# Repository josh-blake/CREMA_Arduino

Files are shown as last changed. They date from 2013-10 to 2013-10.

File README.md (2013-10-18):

CREMA
=====

ControlleR for Espresso MAchines (http://josh.to/crema)

This entire project (including hardware and software) is distrubuted under the Creative Commons Attribution-NonCommercial-ShareAlike 3.0 Unported License.
http://creativecommons.org/licenses/by-nc-sa/3.0/deed.en_US

Please contact crema at josh dot to if you have any specific questions or would like to contribute to this project.

Enjoy the espresso.

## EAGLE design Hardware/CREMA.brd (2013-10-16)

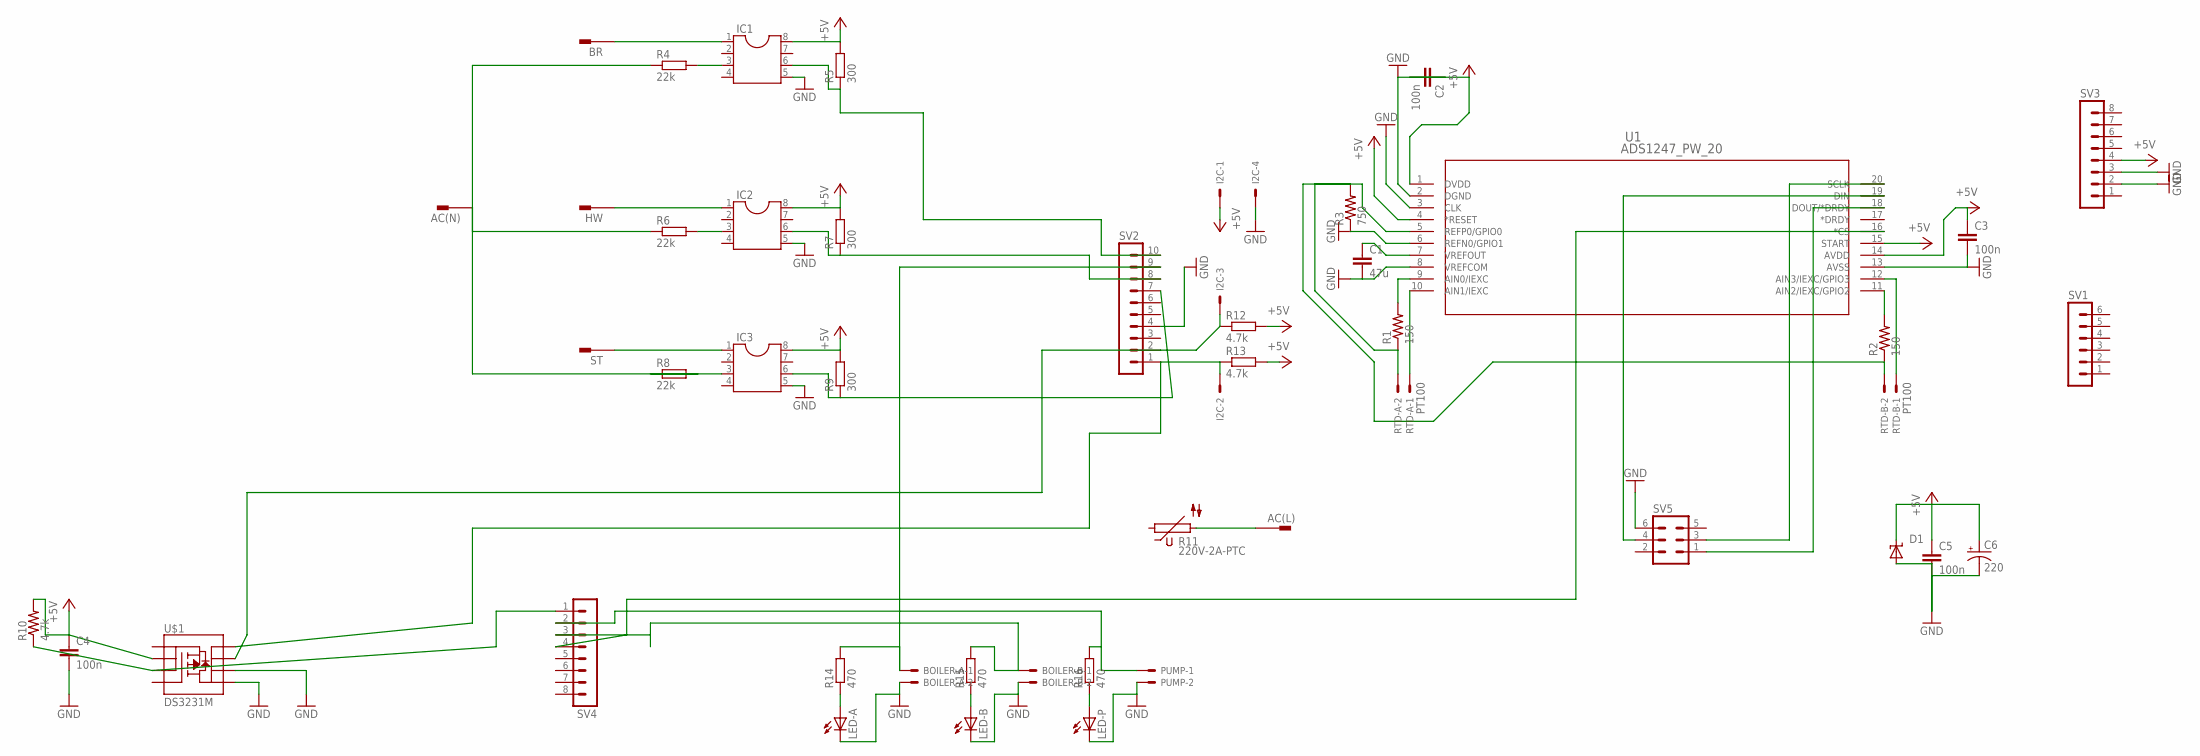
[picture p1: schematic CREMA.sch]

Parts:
AC(L): PIN262409-1; 62409-1
AC(N): PIN262409-1; 62409-1
BOILER-A: C-GRID-02-70543; 70543-02
BOILER-B: C-GRID-02-70543; 70543-02
BR: PIN262409-1; 62409-1
C1: 47u; C0805
C2, C3, C4, C5: 100n; C0805
C6: 220; D/7343-31W
D1: SUPPRESSOR-SMBJ; SMBJ
HW: PIN262409-1; 62409-1
I2C: C-GRID-04-70543; 70543-04
IC1, IC2, IC3: DIL8; DIL08
LED-A: LEDSML0603; SML0603
LED-B: LEDSML0603; SML0603
LED-P: LEDSML0603; SML0603
PUMP: C-GRID-02-70543; 70543-02
R1, R2: 150; R0603
R3: 750; R0603
R4, R6, R8: 22k; R1206
R5, R7, R9: 300; R1206
R10, R12, R13: 4.7k; R0603
R11: 220V-2A-PTC; S20K11
R14, R15, R16: 470; R0603
RTD-A: PT100; 70543-02
RTD-B: PT100; 70543-02
ST: PIN262409-1; 62409-1
SV1: MA06-1
SV2: MA10-1
SV3, SV4: MA08-1
SV5: MA03-2
U1: ADS1247_PW_20; PW20
U$1: DS3231M; SO08

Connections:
+5V: C2.2, C3.1, C4.1, C5.1, C6.+, D1.C, I2C.1, IC1.8, IC2.8, IC3.8, R5.2, R7.2, R9.2, R10.2, R12.2, R13.2, SV3.4, U1.1 (DVDD), U1.4 (*RESET), U1.14 (AVDD), U1.15 (START), U$1.2 (S)
GND: BOILER-A.2, BOILER-B.2, C1.2, C2.1, C3.2, C4.2, C5.2, C6.-, D1.A, I2C.4, IC1.5, IC2.5, IC3.5, LED-A.C, LED-B.C, LED-P.C, PUMP.2, R3.1, SV2.4, SV3.2, SV3.3, SV5.6, U1.2 (DGND), U1.3 (CLK), U1.6 (REFN0/GPIO1), U1.8 (VREFCOM), U1.13 (AVSS), U$1.5 (D), U$1.6 (D)
unnamed: I2C.3, R12.1, SV2.2, U$1.7 (D)
unnamed: C1.1, U1.7 (VREFOUT)
unnamed: RTD-A.1, U1.10 (AIN1/IEXC)
unnamed: R1.1, R2.1, R3.2, RTD-A.2, RTD-B.2, U1.5 (REFP0/GPIO0)
unnamed: R1.2, U1.9 (AIN0/IEXC)
unnamed: R2.2, U1.11 (AIN2/IEXC/GPIO2)
unnamed: RTD-B.1, U1.12 (AIN3/IEXC/GPIO3)
unnamed: BR.A1, BR.A2, IC1.1
unnamed: IC1.3, R4.2
unnamed: IC1.6, R5.1, SV2.10
unnamed: HW.A1, HW.A2, IC2.1
unnamed: IC2.3, R6.2
unnamed: IC2.6, R7.1, SV2.8
unnamed: IC3.1, ST.A1, ST.A2
unnamed: IC3.3, R8.1
unnamed: IC3.6, R9.1, SV2.7
unnamed: AC(N).A1, AC(N).A2, R4.1, R6.1, R8.2
unnamed: R10.1, SV4.1, U$1.3 (S)
unnamed: AC(L).A1, AC(L).A2, R11.2
unnamed: LED-A.A, R14.1
unnamed: SV4.4, U1.16 (*CS)
unnamed: SV5.1, U1.18 (DOUT/*DRDY)
unnamed: SV5.3, U1.20 (SCLK)
unnamed: SV5.4, U1.19 (DIN)
unnamed: I2C.2, R13.1, SV2.1, U$1.8 (D)
unnamed: BOILER-A.1, R14.2, SV2.9
unnamed: BOILER-B.1, R15.2, SV4.3
unnamed: PUMP.1, R16.2, SV4.2
unnamed: LED-B.A, R15.1
unnamed: LED-P.A, R16.1

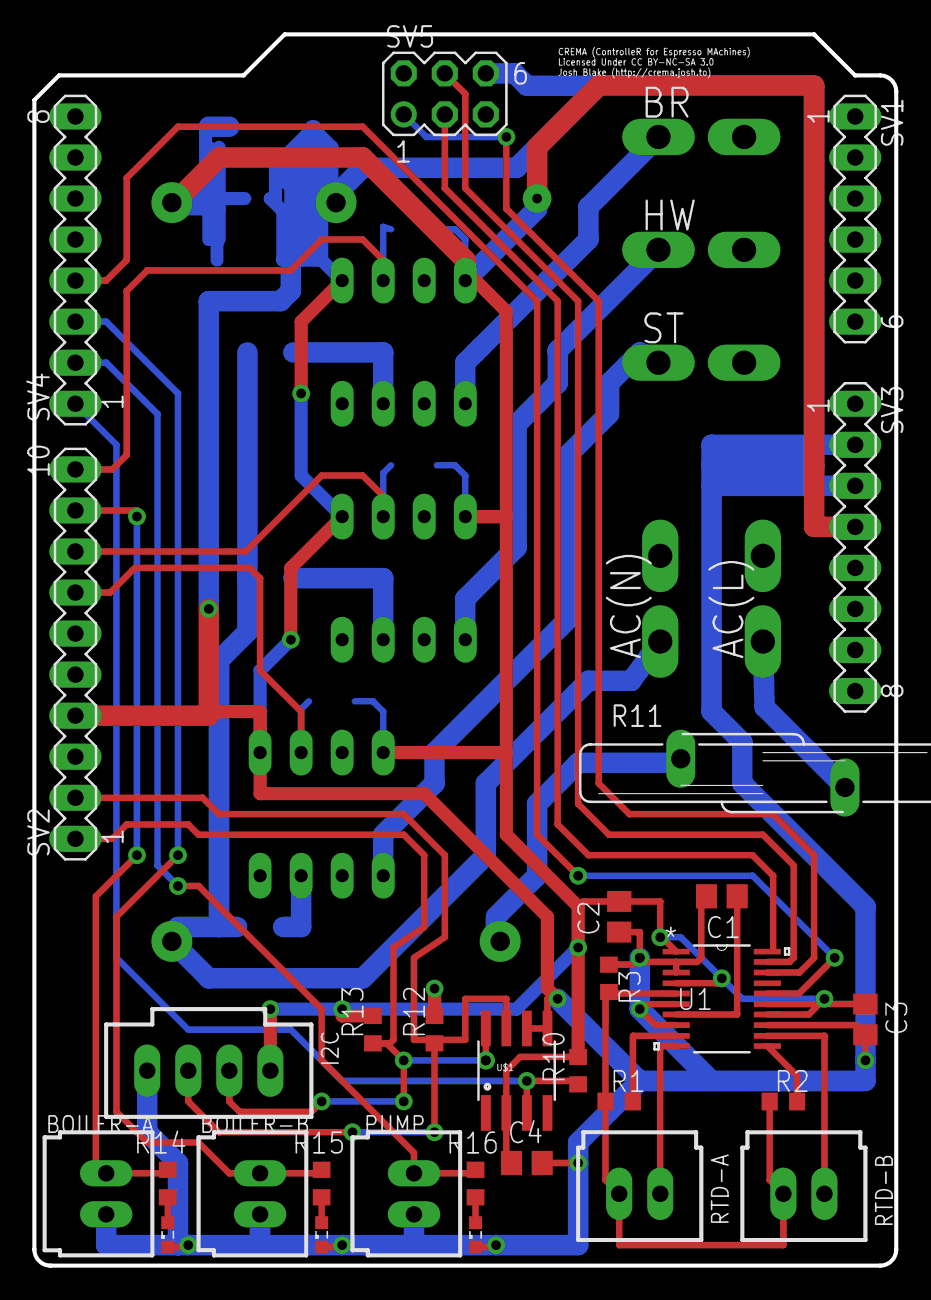
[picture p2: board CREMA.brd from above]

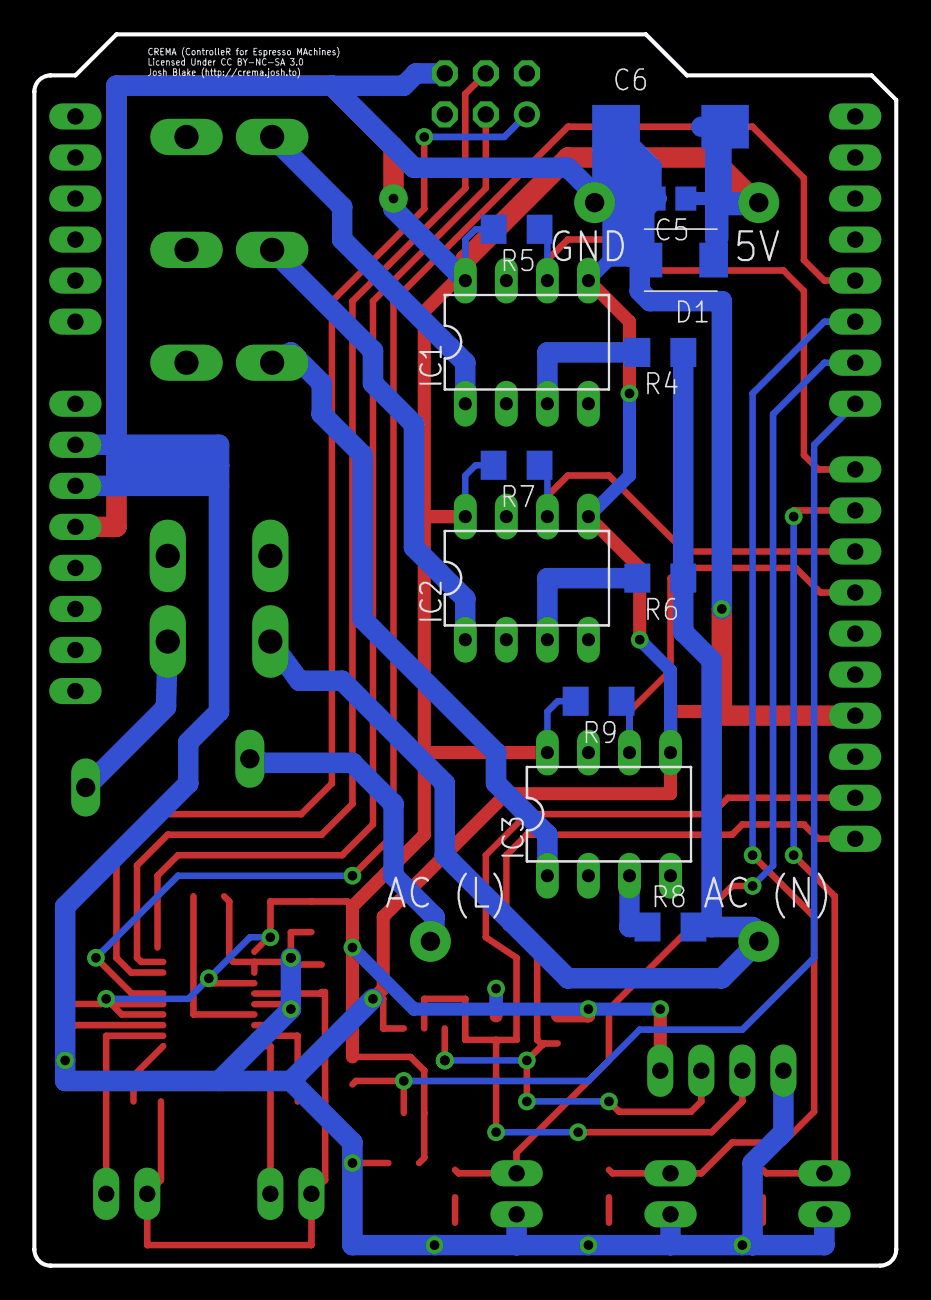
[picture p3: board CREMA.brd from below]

Board: 2 copper layers, 53.3 x 76.2 mm, 47 parts (12 on the bottom side), 32 nets.

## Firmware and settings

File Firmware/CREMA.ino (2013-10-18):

/*
ControlleR for Espresso MAchines - CREMA (C) 2013 http://josh.to/crema
By Josh Blake
Version 0.1

This software is distrubuted under the Creative Commons Attribution-NonCommercial-ShareAlike 3.0 Unported License.
http://creativecommons.org/licenses/by-nc-sa/3.0/deed.en_US
*/

#include <SPI.h>
#include <Wire.h>
#include <avr/eeprom.h>
#include "pid.c"
#include "CrystalFontz.h"

#define BOILERA
//#define BOILERB
#define MENU

#define PID_RANGE 15

//PT100 Configuration & Thermal Constants - Old Values
//#define CVDA 3.9083E-3 //Callendar Van Dusen Constant A
//#define CVDB -5.775E-7 //Callendar Van Dusen Constant B
#define CVDA 3.9083E-3
#define CVDB -5.775E-7

//ADS1247 LSB and Reference Values
#define ADRBIAS 750 //Bias Resistor Value - Theoretical: 750
#define ADRO 150 //Reference Resistance - Theoretical: 150
#define ADIDAC 0.0015 //IDAC Current in Amps
#define ADPGA 32 //AD PGA Setting
//#define ADLSB ( ( (ADRBIAS * 2 * ADIDAC) / ( 2 ^ 23 - 1) ) / ( ADIDAC * ADPGA ) ) //Define AD LSB
#define ADLSB 5.5879361138267652781921956768269153627056315786399339008E-6

//Define Max and Mins
#define MAX_TEMP 150.0
#define MIN_TEMP 0.0
#define MAX_TIME 999.9
//#define MIN_TIME 0.0

//Define LCD Button Masks
#define KP_UP 0x01
#define KP_OK 0x02
#define KP_CANCEL 0x04
#define KP_LEFT 0x08
#define KP_RIGHT 0x10
#define KP_DOWN 0x20

//Define Volatile Variables
volatile boolean INTAL;
volatile boolean INTSW;
volatile uint8_t PB;
volatile uint32_t time = 0;
volatile uint32_t timeLoop = 0;
volatile uint32_t timeSleep = 0;
volatile uint8_t mode = 2;

char lcdBuffer[4][17];
//Define Custom Characters
unsigned char custChar0[] =  //Thermometer
{
  0b00000100,
  0b00001010,
  0b00001010,
  0b00001110,
  0b00011111,
  0b00011111,
  0b00001110,
  0b00000000
};

unsigned char custChar1[] =   //Brew
{
  0b0011000,
  0b0010100,
  0b0011000,
  0b0010110,
  0b0011101,
  0b0000110,
  0b0000101,
  0b0000000
};

unsigned char custChar2[] =  //Hot Water
{
  0b0010100,
  0b0011100,
  0b0010100,
  0b0010100,
  0b0001001,
  0b0001101,
  0b0001010,
  0b0000000
};

unsigned char custChar3[] =  //Steam
{
  0b0001100,
  0b0010000,
  0b0001000,
  0b0000111,
  0b0011010,
  0b0000010,
  0b0000010,
  0b0000000
};

CrystalFontz LCD = CrystalFontz();

//Define Custom Structs
typedef struct DSM3231M
{
  uint8_t address;
  
  uint8_t h;
  uint8_t m;
  uint8_t s;
  boolean p;
  boolean mode;
  
  uint8_t a1h;
  uint8_t a1m;
  uint8_t a1s;
  boolean a1p;
  boolean a1en;

  void setInt(uint8_t val)
  {
    Wire.beginTransmission(0xD0>>1);
    Wire.write(0x0F);
    Wire.write(val);
    Wire.endTransmission();
  }
  
  uint8_t getInt()
  {
    Wire.beginTransmission(0xD0>>1);
    Wire.write(0x0F);
    Wire.endTransmission();
    Wire.requestFrom(address>>1, 1, true);
    return Wire.read();
  }
  
  void getTime()
  {
    Wire.beginTransmission(address>>1);
    Wire.write(0x00);
    Wire.endTransmission();
    Wire.requestFrom(address>>1, 3, true);
    s = Wire.read();
    m = Wire.read();
    h = Wire.read();
    p = (boolean) (h & (1<<5));
    mode = (boolean) (h & (1<<6));
    h &= 0x1F;
  }
  
  void setTime()
  {
    Wire.beginTransmission(address>>1);
    Wire.write(0x00);
    Wire.write(s);
    Wire.write(m);
    if (mode) //12 Hour Mode
    {
      Wire.write(1<<6 | p<<5 | h);
    }
    else //24 Hour Mode
    {
      Wire.write(h);
    }
    Wire.endTransmission();
  }
  
  void getA1()
  {
    Wire.beginTransmission(address>>1);
    Wire.write(0x07);
    Wire.endTransmission();
    Wire.requestFrom(address>>1, 3, true);
    a1s = 0x7F & Wire.read();
    a1m = 0x7F & Wire.read();
    a1h = 0x7F & Wire.read();
    Wire.beginTransmission(address>>1);
    Wire.write(0x0E);
    Wire.endTransmission();
    Wire.requestFrom(address>>1, 1, true);
    a1en = 0x1 & Wire.read();
  }
  
  void setA1()
  {
    Wire.beginTransmission(address>>1);
    Wire.write(0x07);
    Wire.write(a1s);
    Wire.write(a1m);
    Wire.write((1<<6) | (a1p<<5) | a1h);
    Wire.write(1<<7);
    Wire.endTransmission();
    Wire.beginTransmission(address>>1);
    Wire.write(0x0E);
    Wire.write(0b100 | a1en);
    Wire.endTransmission();
  }
  
} DSM3231M_t;

DSM3231M_t rtc;

//Define BOILER struct
typedef struct BOILER
{
  float current_temp;
  float target_temp;
  float K_P;
  float K_I;
  float K_D;
  unsigned int pwm;
  pidData_t pid;
} boiler_t;

typedef struct PUMP
{
  void duty(uint8_t val)
  {
    switch(val)
    {
      case 11: //Marching Soldiers for Steam Boiler ... A pulse every second or so
        TCCR4C &= ~(1<<COM4D0); //Non-inverted PWM output for frequencies less 50% duty
        cli();
        TC4H = 0x3; //Set 10-bit register OCR4C with TOP value 0x28B
        OCR4C = 0xFA;
        TC4H = 0x0; //Set 10-bit register OCR4D with MATCH value
        OCR4D = 0x9;
        sei();
        TCCR4B = (1<<CS43) | (1<<CS43) | (1<<CS41) | (1<<CS40); //Set prescaler to 16384 and start timer
      break;

      case 1:
        TCCR4C &= ~(1<<COM4D0); //Non-inverted PWM output for frequencies less 50% duty
        cli();
        TC4H = 0x2; //Set 10-bit register OCR4C with TOP value 0x28B
        OCR4C = 0x8B;
        TC4H = 0x0; //Set 10-bit register OCR4D with MATCH value
        OCR4D = 0x43; //0x43, 0x84, 0xC5, 0x106, 0x147
        sei();
        TCCR4B = (1<<CS43) | (1<<CS41) | (1<<CS40); //Set prescaler to 2048 and start timer
      break;
      
      case 2:
        TCCR4C &= ~(1<<COM4D0); //Non-inverted PWM output for frequencies less 50% duty
        cli();
        TC4H = 0x2; //Set 10-bit register OCR4C with TOP value 0x28B
        OCR4C = 0x8B;
        TC4H = 0x0; //Set 10-bit register OCR4D with MATCH value
        OCR4D = 0x84; //0x43, 0x84, 0xC5, 0x106, 0x147
        sei();
        TCCR4B = (1<<CS43) | (1<<CS41) | (1<<CS40); //Set prescaler to 2048 and start timer
      break;
      
      case 3:
        TCCR4C &= ~(1<<COM4D0); //Non-inverted PWM output for frequencies less 50% duty
        cli();
        TC4H = 0x2; //Set 10-bit register OCR4C with TOP value 0x28B
        OCR4C = 0x8B;
        TC4H = 0x0; //Set 10-bit register OCR4D with MATCH value
        OCR4D = 0xC5; //0x43, 0x84, 0xC5, 0x106, 0x147
        sei();
        TCCR4B = (1<<CS43) | (1<<CS41) | (1<<CS40); //Set prescaler to 2048 and start timer
      break;
      
      case 4:
        TCCR4C &= ~(1<<COM4D0); //Non-inverted PWM output for frequencies less 50% duty
        cli();
        TC4H = 0x2; //Set 10-bit register OCR4C with TOP value 0x28B
        OCR4C = 0x8B;
        TC4H = 0x1; //Set 10-bit register OCR4D with MATCH value
        OCR4D = 0x06; //0x43, 0x84, 0xC5, 0x106, 0x147
        sei();
        TCCR4B = (1<<CS43) | (1<<CS41) | (1<<CS40); //Set prescaler to 2048 and start timer
      break;
      
      case 5:
        TCCR4C &= ~(1<<COM4D0); //Non-inverted PWM output for frequencies less 50% duty
        cli();
        TC4H = 0x2; //Set 10-bit register OCR4C with TOP value 0x28B
        OCR4C = 0x8B;
        TC4H = 0x1; //Set 10-bit register OCR4D with MATCH value
        OCR4D = 0x47; //0x43, 0x84, 0xC5, 0x106, 0x147
        sei();
        TCCR4B = (1<<CS43) | (1<<CS41) | (1<<CS40); //Set prescaler to 2048 and start timer
      break;
      
      case 6:
        TCCR4C |= (1<<COM4D0); //Inverted PWM output for frequencies above 50% duty
        cli();
        TC4H = 0x2; //Set 10-bit register OCR4C with TOP value 0x28B
        OCR4C = 0x8B;
        TC4H = 0x1; //Set 10-bit register OCR4D with MATCH value
        OCR4D = 0x06; //0x43, 0x84, 0xC5, 0x106, 0x147
        sei();
        TCCR4B = (1<<CS43) | (1<<CS41) | (1<<CS40); //Set prescaler to 2048 and start timer      
      break;
      
      case 7:
        TCCR4C |= (1<<COM4D0); //Inverted PWM output for frequencies above 50% duty
        cli();
        TC4H = 0x2; //Set 10-bit register OCR4C with TOP value 0x28B
        OCR4C = 0x8B;
        TC4H = 0x0; //Set 10-bit register OCR4D with MATCH value
        OCR4D = 0xC5; //0x43, 0x84, 0xC5, 0x106, 0x147
        sei();
        TCCR4B = (1<<CS43) | (1<<CS41) | (1<<CS40); //Set prescaler to 2048 and start timer
      break;
      
      case 8:
        TCCR4C |= (1<<COM4D0); //Inverted PWM output for frequencies above 50% duty
        cli();
        TC4H = 0x0; //Set 10-bit register OCR4D with MATCH value
        OCR4D = 0x43; //0x43, 0x84, 0xC5, 0x106, 0x147
        TC4H = 0x1; //Set 10-bit register OCR4C with TOP value 0x28B
        OCR4C = 0x47;
        sei();
        TCCR4B = (1<<CS43) | (1<<CS41) | (1<<CS40); //Set prescaler to 2048 and start timer
      break;
      
      case 9:
        TCCR4C |= (1<<COM4D0); //Inverted PWM output for frequencies above 50% duty
        cli();
        TC4H = 0x0; //Set 10-bit register OCR4D with MATCH value
        OCR4D = 0x43; //0x43, 0x84, 0xC5, 0x106, 0x147
        TC4H = 0x2; //Set 10-bit register OCR4C with TOP value 0x28B
        OCR4C = 0x8B;
        sei();
        TCCR4B = (1<<CS43) | (1<<CS41) | (1<<CS40); //Set prescaler to 2048 and start timer
      break;
      
      case 10:
        TCCR4C |= (1<<COM4D0); //Inverted PWM output for frequencies above 50% duty
        cli();
        TC4H = 0x2; //Set 10-bit register OCR4C with TOP value 0x28B
        OCR4C = 0x8B;
        TC4H = 0x0; //Set 10-bit register OCR4D with MATCH value
        OCR4D = 0x00; //0x43, 0x84, 0xC5, 0x106, 0x147
        sei();
        TCCR4B = (1<<CS43) | (1<<CS41) | (1<<CS40); //Set prescaler to 2048 and start timer
      break;
      
      default:
        TCCR4C &= ~(1<<COM4D0); //Inverted PWM output for frequencies above 50% duty
        cli();
        TC4H = 0x2; //Set 10-bit register OCR4C with TOP value 0x28B
        OCR4C = 0x8B;
        TC4H = 0x0; //Set 10-bit register OCR4D with MATCH value
        OCR4D = 0x00; //0x43, 0x84, 0xC5, 0x106, 0x147
        sei();
        TCCR4B = (1<<CS43) | (1<<CS41) | (1<<CS40); //Set prescaler to 2048 and start timer
      break;
    }
  }
} pump_t;

typedef struct PRESET
{
  float tempA;
  float tempB;
  float duration;
  uint8_t duty;
} preset_t;

typedef struct PRESETINDEX
{
  char name[17];
  preset_t* preset;
  uint8_t length;
} presetIndex_t;

//Define Presets
const preset_t presetSleep[] = {0, 0, 0, 0};
const preset_t presetWarm[] = {75, 0, 0, 0};

preset_t presetBR[] = {103.0, 0, -1, 10};
preset_t presetHW[] = {95.0, 0, -1, 10};
preset_t presetST[] = {150.0, 150.0, -1, 0};

preset_t preset0[] = {103.0, 0, 4, 6, 103.0, 0, 3, 0, 103.0, 0, -1, 10};
preset_t preset1[] = {103.0, 0, -1, 6, 103.0, 0, 3, 0, 103.0, 0, -1, 10};
preset_t preset2[] = {103.0, 0, 0, 0, 103.0, 0, 0, 0, 103.0, 0, -1, 10};

//Define Preset Index
presetIndex_t presetIndex[] = 
{
  "Hot Water",
  (preset_t*)&presetHW,
  1,
  
  "Manual Brew",
  (preset_t*)&presetBR,
  1,

  "Preset 1",
  (preset_t*)&preset0,
  3,
  
  "Preset 2",
  (preset_t*)&preset1,
  3,
  
  "Preset 3",
  (preset_t*)&preset2,
  3,
};

//Point to Current Preset
uint8_t activePresetIndex = 1;
uint8_t activePresetStep = 0;
preset_t* activePreset = (preset_t*)presetIndex[1].preset;

//Define Boilers
boiler_t boilerA;
boiler_t boilerB;

//Point to Working Boiler A
boiler_t* activeBoilerA = &boilerA;

//Point to Working Boiler B
boiler_t* activeBoilerB = &boilerB;

//Define Pump
pump_t pump;

//Point to Working Pump
pump_t* activePump = &pump;

#ifdef MENU
//Define Menu Element
typedef struct MENUELEMENT
{
  void* L0_func; const void* L0_args;
  void* L1_func; const void* L1_args;
  void* K_func; const void* K_args;
  void* L_func; const void* L_args;
  void* R_func; const void* R_args;
  void* U_func; const void* U_args;
  void* D_func; const void* D_args;
} menuElement_t;

//Null Argument
PROGMEM const void* const MA_null[] = {};

// 0 Arguments
PROGMEM const void* const MA0_L0[] = {(char*)&lcdBuffer[0], (char*)"Edit Presets"};
PROGMEM const void* const MA0_L1[] = {(char*)&lcdBuffer[1], (char*)""};
PROGMEM const void* const MA0_K[] = {(void*)9};
PROGMEM const void* const MA0_L[] = {(void*)8};
PROGMEM const void* const MA0_R[] = {(void*)1};

//1 Arguments
PROGMEM const void* const MA1_L0[] = {(char*)&lcdBuffer[0], (char*)"Edit PID"};
PROGMEM const void* const MA1_L1[] = {(char*)&lcdBuffer[1], (char*)"Parameters"};
PROGMEM const void* const MA1_L[] = {(void*)0};
PROGMEM const void* const MA1_R[] = {(void*)2};

//2 Arguments
PROGMEM const void* const MA2_L0[] = {(char*)&lcdBuffer[0], (char*)"Set Clock"};
PROGMEM const void* const MA2_L1[] = {(char*)&lcdBuffer[1], (char*)""};
PROGMEM const void* const MA2_K[] = {(void*)59};
PROGMEM const void* const MA2_L[] = {(void*)1};
PROGMEM const void* const MA2_R[] = {(void*)3};

//3 Arguments
PROGMEM const void* const MA3_L0[] = {(char*)&lcdBuffer[0], (char*)"Set Wakeup Time"};
PROGMEM const void* const MA3_L1[] = {(char*)&lcdBuffer[1], (char*)""};
PROGMEM const void* const MA3_K[] = {(void*)62};
PROGMEM const void* const MA3_L[] = {(void*)2};
PROGMEM const void* const MA3_R[] = {(void*)4};

//4 Arguments
PROGMEM const void* const MA4_L0[] = {(char*)&lcdBuffer[0], (char*)"Set Sleep Delay"};
PROGMEM const void* const MA4_L1[] = {(char*)&lcdBuffer[1], (char*)""};
PROGMEM const void* const MA4_L[] = {(void*)3};
PROGMEM const void* const MA4_R[] = {(void*)5};
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
void loop()
{
  timeLoop = millis();
  
  if (INTAL) //Alarm Interrupt Goto Mode 2 and Update Sleep Timeout
  {
    INTAL = false;
    if (rtc.getInt() & 0x01)
    {
      mode = 2;
      timeSleep = millis();
    }
    rtc.setInt(0x00); //Clear all flags
  }

  //Test if a Switch Interrupt has Occurred and Update Sleep Timeout 
  if (INTSW)
  {
    INTSW = false;
    timeSleep = millis();
  }
  
  //Test for Keypad Button Presses and Update Sleep Timeout
  LCD.getKP();
  if (LCD.KP[1]) {timeSleep = millis();}
  
  //Manage Sleep Timeout
  if ((millis() - timeSleep) > 5400000) {mode = 0;}//Two-hour timeout 7200000, 1.5 5400000
  
  //Get the time from the RTC
  rtc.getTime();
  
  //Default Display - Can be superceded!
  sprintf((char*)&lcdBuffer[0], "%.1f%cC %c %02hhX:%02hhX%c", activeBoilerA->current_temp, 0xDF, (PINB & 1<<PINB5) ? 0x01 : 0x20, rtc.h, rtc.m, rtc.p ? 'p' : 'a');
  sprintf((char*)&lcdBuffer[1], "");
  
  switch (mode)
  {
    case 0: //Deep Sleep
      activePreset = (preset_t*)&presetSleep[0]; //Point to Sleep Preset
      sprintf((char*)lcdBuffer[1], "Sleep"); //Render Display
      if (LCD.KP[1]) {mode = 2;}
    break;
    
    case 1: //Stand By
    
    break;
    
    case 2: //Idle Mode
      if (LCD.KP[1] & KP_CANCEL) {mode = 0;}
      if (LCD.KP[1] & (KP_OK | KP_LEFT | KP_RIGHT)) {mode = 7;} //Check for User OK
      if (LCD.KP[1] & KP_DOWN) {if (activePresetIndex+1 < sizeof(presetIndex)/sizeof(presetIndex_t)) {activePresetIndex++;}} //Check for User DOWN
      if (LCD.KP[1] & KP_UP) {if (activePresetIndex-1 >= 0) {activePresetIndex--;}} //Check for User UP
     
      activePresetStep = 0;
      activePreset = presetIndex[activePresetIndex].preset; //Point back to beginning of Preset
      
      sprintf((char*)lcdBuffer[1], "%-15s", presetIndex[activePresetIndex].name); //Render Display
    break;
    
    case 3: //Brew Mode
      if (activePresetStep == 0) //At the beginning of the preset?
      {
        activePreset = presetIndex[activePresetIndex].preset; //Point back to beginning of brew preset
        activePresetStep = 1;
        time = millis();
      }
      else
      { 
        if (activePreset->duration != -1) //Timed Preset?
        {
          if(((float)(millis()-time))/1000 > activePreset->duration) //Is the time up?
          {
            if (presetIndex[activePresetIndex].length > activePresetStep) //Are there more steps in the Preset?
            {
              activePreset++;
              activePresetStep++;
              time = millis();
            }
            else //No more steps in the current Preset, go to Idle
            {
              mode = 2;
            }
          }
          else
          {
            if (LCD.KP[1] & KP_OK) //Check for User OK, Force next step
            {
              if (presetIndex[activePresetIndex].length > activePresetStep) //Are there more steps in the Preset?
              {
                activePreset++;
                activePresetStep++;
                time = millis();
              }
              else //No more steps in the current Preset, go to Idle
              {
                mode = 2;
              }
            }
            sprintf((char*)lcdBuffer[1], "Step %hhu (%3.1fs)", activePresetStep, ((float)(millis() - time))/1000); //Render Display
          }
        }
        else
        {
          if (LCD.KP[1] & KP_OK) //Check for User OK
          {
            if (presetIndex[activePresetIndex].length > activePresetStep) //Are there more steps in the Preset?
            {
              activePreset++;
              activePresetStep++;
              time = millis();
            }
            else //No more steps in the current Preset, go to Idle
            {
              mode = 2;
            }
          }
          sprintf((char*)lcdBuffer[1], "Step %hhu (%3.1fs)", activePresetStep, ((float)(millis() - time))/1000); //Render Display
        }
      }
    break;
    
    case 4: //Hot Water Mode
      activePreset = (preset_t*)&presetHW[0]; //Point to Manual Brew Preset
      sprintf((char*)lcdBuffer[1], "Hot Water"); //Render Display
    break;
    
    case 5: //Steam Mode
      activePreset = (preset_t*)&presetST[0]; //Point to Steam Preset
      activePreset->duty = 0; //Turn off Pump
      sprintf((char*)lcdBuffer[1], "Steam"); //Render Display
    break;

    case 6: //Steam Mode w/ Marching Soldiers
      activePreset = (preset_t*)&presetST[0]; //Point to Steam Preset
      activePreset->duty = 11; //Turn on Marching Soldiers
      sprintf((char*)lcdBuffer[1], "Steam"); //Render Display
    break;
    
    case 7: //Menu Mode
      #ifdef MENU
      //Callback Display Finctions w/ Args
      ((void(*)(...))((PGM_P)pgm_read_word(&curMenuElement->L0_func)))((PGM_P)pgm_read_word(&curMenuElement->L0_args));
      ((void(*)(...))((PGM_P)pgm_read_word(&curMenuElement->L1_func)))((PGM_P)pgm_read_word(&curMenuElement->L1_args));
      //Test for user input and Callback Button Functions w/ Args
      if (LCD.KP[1] & KP_CANCEL) {curMenuElement = (menuElement_t*)&menu[0]; mode = 2;}
      if (LCD.KP[1] & KP_OK) {((void(*)(...))((PGM_P)pgm_read_word(&curMenuElement->K_func)))((PGM_P)pgm_read_word(&curMenuElement->K_args));}
      if (LCD.KP[1] & KP_LEFT) {((void(*)(...))((PGM_P)pgm_read_word(&curMenuElement->L_func)))((PGM_P)pgm_read_word(&curMenuElement->L_args));}
      if (LCD.KP[1] & KP_RIGHT) {((void(*)(...))((PGM_P)pgm_read_word(&curMenuElement->R_func)))((PGM_P)pgm_read_word(&curMenuElement->R_args));}
      if (LCD.KP[1] & KP_UP) {((void(*)(...))((PGM_P)pgm_read_word(&curMenuElement->U_func)))((PGM_P)pgm_read_word(&curMenuElement->U_args));}
      if (LCD.KP[1] & KP_DOWN) {((void(*)(...))((PGM_P)pgm_read_word(&curMenuElement->D_func)))((PGM_P)pgm_read_word(&curMenuElement->D_args));}
      #endif
    break;
  }
  
  if (mode == 3 | mode == 4 | mode == 5 | mode == 6) {activePump->duty(activePreset->duty);} else {activePump->duty(0);} //Turn Pump off when not in use
  
  #ifdef BOILERA
  activeBoilerA->target_temp = activePreset->tempA;
  activeBoilerA->current_temp = LtoT(TCtoL(getADC()));
  
  if (activeBoilerA->current_temp < (activeBoilerA->target_temp - PID_RANGE))
  {
    pid_Reset_Integrator(&activeBoilerA->pid);
    activeBoilerA->pwm = ICR1;
  }
  else if (activeBoilerA->current_temp > (activeBoilerA->target_temp + PID_RANGE))
  {
    pid_Reset_Integrator(&activeBoilerA->pid);
    activeBoilerA->pwm = 0;
  }
  else
  {
    activeBoilerA->pwm = pid_Controller(activeBoilerA->target_temp, activeBoilerA->current_temp, &activeBoilerA->pid);
  }
  if (activeBoilerA->pwm >= ICR1) activeBoilerA->pwm = ICR1;
  if (activeBoilerA->pwm <= 0) activeBoilerA->pwm = 0;
  OCR1A = activeBoilerA->pwm; //OCRnx are double buffered - you don't need to stop the timer to update the MATCH value!
  #endif
  
  #ifdef BOILERB
  activeBoilerB->target_temp = activePreset->tempB;
  activeBoilerB->current_temp = LtoT(TCtoL(getADC()));
  if (activeBoilerB->current_temp < (activeBoilerB->target_temp - PID_RANGE))
  {
    pid_Reset_Integrator(&activeBoilerB->pid);
    activeBoilerB->pwm = ICR1;
  }
  else if (activeBoilerB->current_temp > (activeBoilerB->target_temp + PID_RANGE))
  {
    pid_Reset_Integrator(&activeBoilerB->pid);
    activeBoilerB->pwm = 0;
  }
  else
  {
    activeBoilerB->pwm = pid_Controller(activeBoilerB->target_temp, activeBoilerB->current_temp, &activeBoilerB->pid);
  }
  if (activeBoilerB->pwm >= ICR1) activeBoilerB->pwm = ICR1;
  if (activeBoilerB->pwm <= 0) activeBoilerB->pwm = 0;
  OCR3A = activeBoilerB->pwm;
  #endif
  
  //Update Display
  //Turn off Backlight if in Sleep Mode
  if (mode) {if (LCD.brightness == 0) LCD.setBrightness(2);} else {if (LCD.brightness != 0) LCD.setBrightness(0);}
  
  //Line 0
  sprintf((char*)&lcdBuffer[2], "%-16s", lcdBuffer[0]); //Left Justify and Pad with Spaces for LCD
  LCD.print(lcdBuffer[2], 16, 0, 0);
  
  //Line 1
  sprintf((char*)&lcdBuffer[3], "%-16s", lcdBuffer[1]); //Left Justify and Pad with Spaces for LCD
  LCD.print(lcdBuffer[3], 16, 0, 1);
  
  delay(100 + timeLoop - millis()); //Iterate every 100ms to ensure PID retains accuracy
}

unsigned long getADC() //Will Return 24 Bit Two's Compliment
{
  unsigned long val = 0;
  PORTD &= ~(1<<PORTD4); //Pull SS Low to Enable Communications with ADS1247
  SPI.transfer(0x12); //Issue RDATA
  val |= SPI.transfer(0xFF);
  val <<= 8;
  val |= SPI.transfer(0xFF);
  val <<= 8;
  val |= SPI.transfer(0xFF);
  PORTD |= 1<<PORTD4; //Pull SS High to Disable Communications with ADS1247
  return val;
}

long TCtoL (unsigned long UL) //24 Bit Two's Compliment to 32 Bit Signed Long
{
  if (UL & 0x800000) {UL |= ~0xFFFFFF; UL+=1;}
  return UL;
}
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

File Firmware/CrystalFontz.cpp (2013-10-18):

/*
CrystalFontz Library for Arduino http://josh.to/crema
By Josh Blake
Version 0.1

Description: This software provides basic functionality to communicate with a CrystalFontz CFI-533 TMI (I2C) display module.
Not all functions have been implemented yet.

This software is distrubuted under the Creative Commons Attribution-NonCommercial-ShareAlike 3.0 Unported License.
http://creativecommons.org/licenses/by-nc-sa/3.0/deed.en_US
*/

#include "CrystalFontz.h"
#include <util/crc16.h>

CrystalFontz::CrystalFontz(uint8_t i2c_address)
{
    i2c_addr = i2c_address;	
}

CrystalFontz::CrystalFontz()
{
     i2c_addr = 0x2A;
     brightness = 2;
     contrast = 16;
}

void CrystalFontz::write(COMMAND_PACKET* packet) 
{
    Wire.beginTransmission(i2c_addr);
    Wire.write(packet->command);
    Wire.write(packet->length);
    Wire.write(packet->data, packet->length);
    Wire.write(packet->crc.asByte[0]);
    Wire.write(packet->crc.asByte[1]);
    Wire.endTransmission();
}

void CrystalFontz::print(char* string, uint8_t len, uint8_t col, uint8_t row) 
{
    COMMAND_PACKET packet;
    packet.command = 0x1F;
    packet.length = len + 2;
    packet.data[0] = col;
    packet.data[1] = row;
    for(uint8_t i=0;i<len;i++) packet.data[i+2] = string[i];
    packet.crc.asWord = CRC((uint8_t*)&packet, packet.length+2);
    write((COMMAND_PACKET*)&packet);
    delay(5);
}

/*void CrystalFontz::replyWait(unsigned char command)
{
    COMMAND_PACKET packet;
    while(Wire.requestFrom(i2c_addr,4,true))
    {
        packet.command = Wire.read();
        packet.length = Wire.read();
        packet.crc.asByte[0] = Wire.read();
        packet.crc.asByte[1] = Wire.read();
        if ((command | 0x40) && packet.command) break;
    }
}*/

void CrystalFontz::init() 
{
    clear();
}

void CrystalFontz::clear() 
{
    COMMAND_PACKET packet;
    packet.command = 0x06;
    packet.length = 0;
    packet.crc.asWord = CRC((uint8_t*)&packet, 2);
    write((COMMAND_PACKET*)&packet);
    delay(5);
}

void CrystalFontz::setCharacter(uint8_t char_num, uint8_t* rows) 
{
    COMMAND_PACKET packet;
    packet.command = 0x09;
    packet.length = 9;
    packet.data[0] = char_num;
    for(uint8_t i=0;i<8;i++) packet.data[i+1] = rows[i];
    packet.crc.asWord = CRC((uint8_t*)&packet, 11);
    write((COMMAND_PACKET*)&packet);
    delay(5);
}

void CrystalFontz::setBrightness(uint8_t val) //0 to 100
{
    brightness = val;
    COMMAND_PACKET packet;
    packet.command = 0x0E;
    packet.length = 1;
    packet.data[0] = brightness;
    packet.crc.asWord = CRC((uint8_t*)&packet, 3);
    write((COMMAND_PACKET*)&packet);
    delay(50);
}

/*void CrystalFontz::ping(unsigned char *data, unsigned short len) 
{
    COMMAND_PACKET packet;
    packet.command = 0x00;
    packet.length = len;
    for(unsigned char i=0;i<len;i++) packet.data[i+2] = data[i];
    packet.crc.asWord = CRC((unsigned char*)&packet, packet.length+2);
    write(packet);
}*/

void CrystalFontz::getKP()
{
    COMMAND_PACKET packet;
    packet.command = 0x18;
    packet.length = 0;
    packet.crc.asWord = CRC((uint8_t*)&packet, 2);
    write((COMMAND_PACKET*)&packet);
    delay(2);
    Wire.requestFrom(i2c_addr, 7);
    packet.command = Wire.read();
    packet.length = Wire.read();
    for(uint8_t i = 0; i<packet.length; i++) packet.data[i] = Wire.read();
    packet.crc.asByte[0] = Wire.read();
    packet.crc.asByte[1] = Wire.read();
    if ( CRC((uint8_t*)&packet, packet.length+2) && packet.crc.asWord ) {KP[0] = packet.data[0]; KP[1] = packet.data[1]; KP[2] = packet.data[2];}
}

uint16_t CrystalFontz::CRC(uint8_t *ptr, uint16_t len)
{
    uint16_t crc = 0xFFFF;
    while(len--) crc = _crc_ccitt_update(crc, *ptr++);
    return(~crc);
}

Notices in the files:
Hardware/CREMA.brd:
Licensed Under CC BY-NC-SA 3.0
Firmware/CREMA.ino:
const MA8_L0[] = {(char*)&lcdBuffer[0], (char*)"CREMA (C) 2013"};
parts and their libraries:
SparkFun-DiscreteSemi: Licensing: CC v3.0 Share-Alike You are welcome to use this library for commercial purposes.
